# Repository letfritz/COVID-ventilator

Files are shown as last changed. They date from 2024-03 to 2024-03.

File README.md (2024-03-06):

# Technology at the service of life in combating the COVID-19 pandemic – UFF FRONT in the production of mechanical ventilators  

<div align="center"><br/>
  <div style="display: inline-block;">
    
    
    
  </div>
  <div style="display: inline-block;">
    
    
    
    
    
    
  </div>
</div><br/>

Arduino project for creating a mechanical ventilator for COVID patients.

## 📷 Screenshot
Electrical System Architecture:
electrical_system_architecture

Steps:
Steps

Volume Control State Machine:
Volume_Control_State_Machine

First prototype of a mechanical ventilator assembled at UFF. Emphasis on (a) the structural part of the equipment and (b) the control panel:
first

Detailing the control panel with controls for the Inspiration/Expiration (I/E) ratio, Air Volume Control, and ventilation frequency:
second

## Installation
1. Download the package to a local folder (e.g. ~/DER-SmartCampus/) by running:
  ```
    git clone https://github.com/letfritz/COVID-ventilator.git
  ```
2. Run Arduino IDE and navigate to the folder (~/main/), then run the main.ino script.

## Usage
  - See description in AnáliseDeRequisitos.docx.

## License
Released under MIT license.

## 📝 About this Project
The project aims primarily to promote the supply of emergency mechanical ventilation equipment, mainly for the public health system (SUS), to patients affected by comorbidities caused by COVID-19. These devices are necessary when severe pneumonia compromises lung function, and the breathing process is carried out with immense effort (dyspnea), reducing the concentration of dissolved oxygen in the blood (hypoxemia). In critical cases of COVID-19, intubation and immediate use of mechanical ventilation are indicated.

Initiatives around the world have emerged for the development of manual mechanical breathing units (AMBU). Some of the most famous examples are the projects developed at Oxford  and MIT ; in Brazil, projects such as the one from COPPE at UFRJ  and at USP  stand out. Among all these devices, the MIT model stands out for being a project that has undergone numerous tests and has been developed since 2010, featuring low-cost components. Additionally, after the onset of the pandemic, the working group has been making adaptations to make the project more robust and safe.

The E-Vent mechanical ventilator functions as a low-cost portable ventilator. Its main function is to assist the patient in breathing. Its construction uses few parts and has low manufacturing complexity. Mechanical force is exerted by a direct current motor coupled to a gear, which in turn moves the rods, compressing the AMBU, also known as a manual resuscitator or self-inflating bag. The AMBU is a manual device that provides positive pressure ventilation for patients who do not breathe or do so inadequately. The compression and expansion cycle of the AMBU, performed by the motor rotation, is controlled by the electronic part of the E-Vent and can be customized according to each patient's respiratory needs.

At UFF, adaptations to the E-Vent project have been developed. The main proposed changes are in the project's electronics and some adaptations in the mechanical structure to accommodate motors with other hole patterns and electrical specifications, which can be found domestically. A first prototype was built to evaluate the assembly and refine each part of the mechanical structure of the project. These parts will be manufactured using a CNC Machining Center to reduce costs with the projects. In addition, tests of precision in controlling the volume and pressure of the air pumped by the AMBU through motor rotation were also carried out during development.

The project is currently in the phase of building the second prototype and drafting a document to be submitted to ANVISA for certification of the final equipment. To do this, all standards regarding ventilation modes required by the agency will be followed so that the product can quickly meet the current demand.

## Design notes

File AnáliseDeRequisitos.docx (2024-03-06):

Componentes Eletrônicos

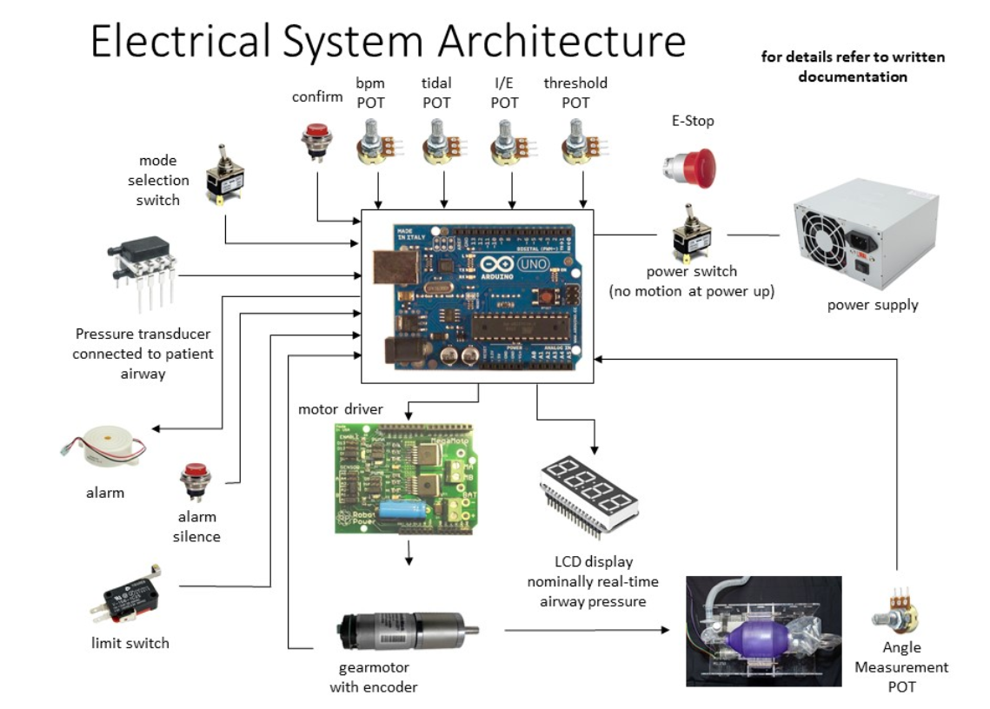
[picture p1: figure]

# 1 Materiais Listados para Uso

E-Vent MIT | E-Vent Adaptado | Função
Sensor Fim de Curso | Sensor Fim de Curso | Limitar a rotação do ponto de partida do motor
Botão de Alarme | Botão | Botão ao pressionar desliga o alarme
Alarme | Alarme | Alarme ao identificar falha
Transdutor de pressão conectado às vias aéreas do paciente | ? | Monitora a pressão que chega ao paciente
Chave de seleção | Chave de seleção | Seleção de modo do volume para auxiliar no controle.
Botão de Confirmação | Botão de Confirmação | Usado para confirmar uma alteração em um dos potenciômetros. Esse é um recurso de segurança necessário.
Potenciômetro (10 kΩ) BPM | Potenciômetro (10 kΩ) BPM | Varia o BPM. Isso define a taxa de 8 ao BPM máximo.
Potenciômetro (10 kΩ) Tidal | Potenciômetro (10 kΩ) Tidal | Varia o volume inspirado, define a oscilação angular dos braços. Durante a operação, cada braço varia aproximadamente um máximo de 20° (apertar totalmente uma bolsa grande). Este mostrador varia de posição de 0% (totalmente aberto) a 100% (totalmente compactado).
Potenciômetro (10 kΩ) I/E | Potenciômetro (10 kΩ) I/E | Varia a proporção I:E. Varia de 1:1 a 1:4.
Potenciômetro (10 kΩ) Threshold | Potenciômetro (10 kΩ) Threshold | Define o limite de pressão para detectar o controle de assistência.
Potenciômetro (10 kΩ) Ângulo | Potenciômetro (10 kΩ) Ângulo | ?
Botão E-Stop | Botão E-Stop | Desativa instantaneamente o sistema. Isso permitirá que a bolsa seja removida.
Chave de Energia | Chave de Energia | ON/OFF
Display LCD | Display LCD | Exibe a pressão das vias aéreas em cm H2O. Display LCD de 20 × 4 caracteres.
Drive do Motor | ?
Caixa de Redução do Motor com Encoder | ?
AMBU | AMBU | Pulmão artificial
Fonte | Fonte | Liga o sistema E-Vent

# 2 Metodologia

## 2.1 Estado de Controle de Volume

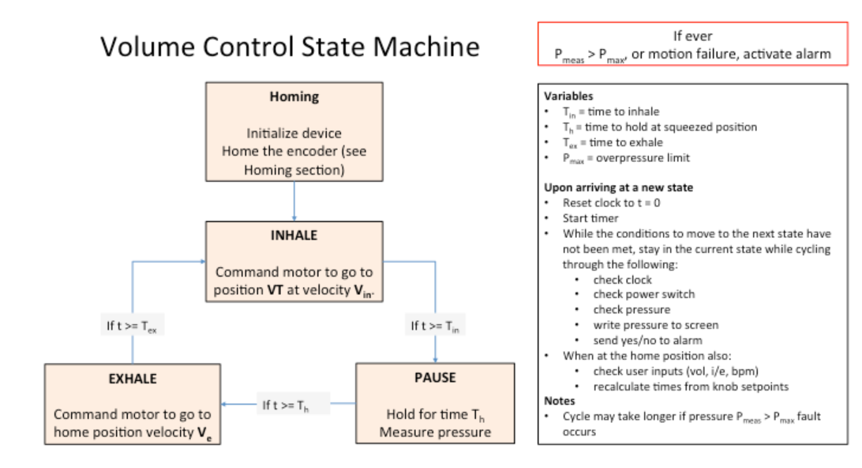
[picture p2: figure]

Tempo t é a quantidade de tempo gasto no estado atual.

### 2.1.1 Período (T)

O período de tempo (em segundos) de um ciclo de inspiração / expiração.

T=60/(BPM)

Sendo, BPM a respirações por minuto, também chamadas de frequência respiratória (RR). Geralmente varia entre 8-30 BPM. Isso é definido pelo potenciômetro.

### 2.1.2 Tin

O período de tempo (em segundos) da fase inspiratória.

T_(in) =T/((1+IE))

Sendo, IE a proporção entre Inspiração e Expiração definida pelo potenciômetro I:E. Por exemplo: se I/E é 1:3, então IE=3 .

### 2.1.3 Tex

O período de tempo (em segundos) da fase expiratória.

T_(ex) =T-T_(in)

### 2.1.4 Vin

A taxa de rotação da fase inspiratória (em pulsos / segundo).

V_(in) =(VT)/(T_(in))

## 2.2 Parâmetros Definidos pelo Usuário

### 2.2.1 Th

A quantidade de tempo (em segundos) para manter a compressão no final da inspiração para a pressão do platô.

### 2.2.2 Ve

A velocidade dos dedos na fase expiratória (em pulsos / segundo). Observe que, durante a expiração, nosso dispositivo não controla a vazão do paciente. Essa velocidade é simplesmente a velocidade da abertura dos dedos e não está relacionada à taxa de fluxo expiratório.

### 2.2.3 Pmax

A pressão máxima permitida (configurada para 40 cmH20).

### 2.2.4 Existem três parâmetros de pressão

Os parâmetros mensuráveis que devem ser levados em consideração

- Pip: Pressão máxima durante a inspiração. Consideramos 40 cmH20 o limite de pressão superior para segurança. Isso também corresponde ao limite da válvula de liberação de sobrepressão em alguns sacos Ambu.
- Pplat: A pressão de platô da inspiração. Um número de diagnóstico importante para os médicos.
- PEEP: A pressão residual no sistema após a expiração. Nós não controlamos diretamente esse valor, mas ele geralmente é controlado manualmente por meio de uma válvula PEEP no Ambu Bag.

## 2.3 Etapas

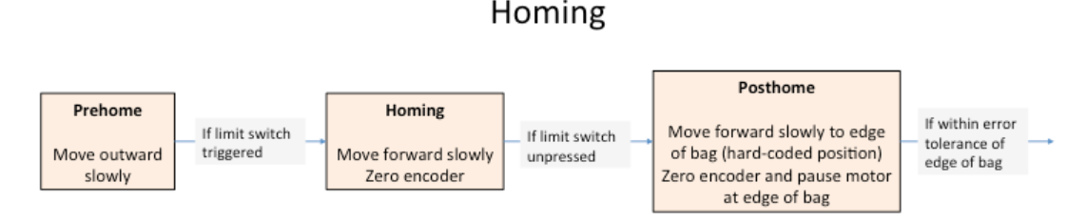
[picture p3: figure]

Durante a fase de configuração, inicializamos o programa, iniciamos a comunicação serial com o controlador do motor e inicializamos o codificador.

Na fase inspiratória, comandamos o motor para ir para a posição VT na velocidade Vin. Após Tin segundos, passamos para o estado de pausa.

No estado de pausa, mantemos o tempo Th e medimos a pressão do platô. Em seguida, passamos para a fase expiratória.

Na fase expiratória, comandamos o motor para ir para a posição 0 na velocidade Ve. Depois do tempo Tex, voltamos à fase inspiratória.

## 2.4 Pressão de Platô

Cada vez que os braços se fecham, implementamos uma pausa de 0,15s antes de abrir. Isso não afeta a razão I/E, mas é necessário reter o ar no paciente. Durante esta fase, a pressão das vias aéreas é medida e exibida. Isso indica "pressão de platô" e orientará a tomada de decisão clínica. Essa pressão será exibida até o próximo ciclo e atualização. Outras pressões são menos importantes, mas podem ser tratadas em uma estratégia de controle mais complicada.

## 2.5 Funções de alarmes

Todos os alarmes devem alertar o clínico de maneira simples, concisa e clara, para que o clínico possa decidir como proceder. Por exemplo, uma falha mecânica requer uma resposta clínica diferente da de um paciente que para de respirar no modo de assistência.

Lista de Alarmes:

Nome do Alarme | Detecção | Condição de Avaliação | Tom | Ação Clínica | Mensagem do Display LCD
Pressão PIP excedida | Isso garante que a unidade nunca possa fornecer ar a uma pressão superior a 40 cmH20 para reduzir o risco de barotrauma (danos nos pulmões). | Um ciclo respiratório completo sem pressão excessiva | Tom de emergência | Interrompa imediatamente a compressão, abra completamente, retome a operação normal no início do ciclo respiratório | ALTA PRESSÃO
Falha de Sobrecorrente | Este alarme detecta o motor sendo pressionado com muita força. Isso indica que algo pode estar preso no mecanismo ou pode haver um bloqueio no tubo respiratório. | Um ciclo respiratório completo sem evento de sobrecorrente | Tom de emergência | Interrompa imediatamente a compressão, abra completamente, retome a operação normal no início do ciclo respiratório | FALHA DE SOBRECORRENTE
Sob Pressão | Este alarme detecta qualquer desconexão ou vazamento e notifica o médico para verificar o tubo de respiração. | Pressão de platô medida normal | Tom de emergência | Continuar a operação normal | BAIXA PRESSÃO, DESCONECTADO?
Pressão de Condução Excedida | Este alarme notifica o clínico de que há resistência incomum no tubo respiratório ou nas vias aéreas do paciente. | Uma medição de pressão de condução na faixa normal | Notificação | Continue a operação normal | ELEVADO PICO DE PRESSÃO
Volume corrente não entregue | O codificador indica falha ao atingir a posição rotacional desejada | Volume corrente entregue na faixa correta | Tom de emergência | Continue a operação normal | VOLUME CORRENTE NÃO MEDIDO
Pressão corrente não detectada | Este alarme detecta situações em que a pressão não reflete inspiração, mas pode não haver um vazamento. Por exemplo, se a bolsa for removida da máquina. | Um ciclo respiratório completo sem falha da pressão corrente | Tom de emergência | Continue a operação normal | SEM PRESSÃO CORRENTE

## 2.6 Botão de Alarme

O botão de silêncio do alarme deve silenciar apenas o tom do alarme, a notificação visual deve permanecer. Todos os alarmes devem ser silenciados por dois minutos, mesmo que um novo alarme seja acionado, o silêncio do alarme deve ser mantido. Pressionar o botão de silêncio do alarme novamente, antes de decorridos dois minutos, deve silenciar os alarmes.

Se vários alarmes estiverem ativos, eles deverão ser exibidos visualmente com os LEDs. Na tela, as mensagens devem circular.

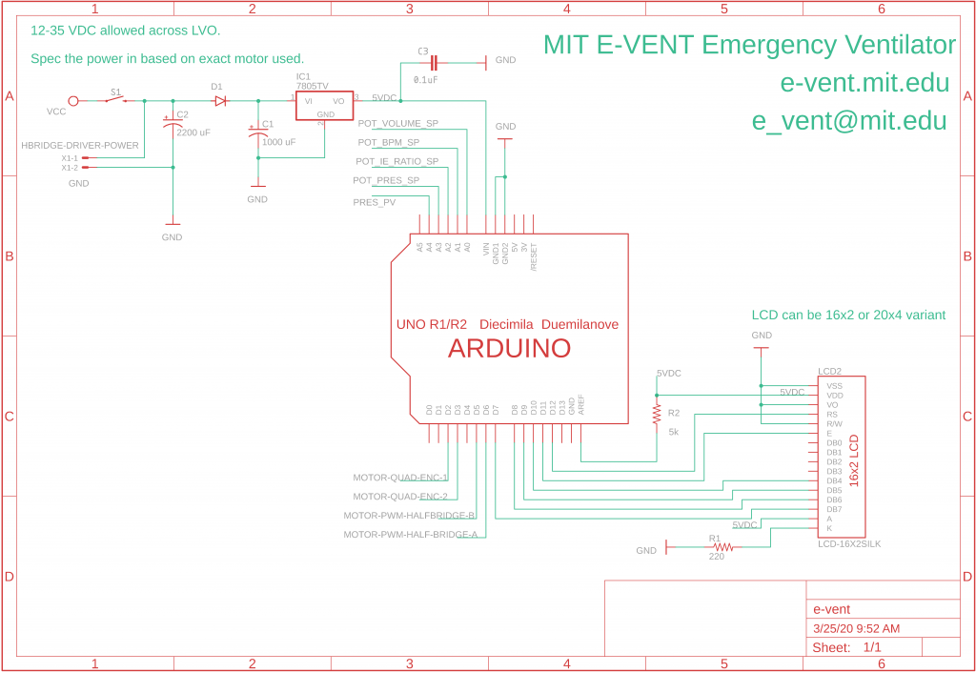
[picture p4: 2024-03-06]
Circuito_Eletronico/controls-schematic-arduino-hbridge-1024x706.png

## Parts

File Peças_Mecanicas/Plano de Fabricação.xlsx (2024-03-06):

PEÇA | QTD | MATERIAL | PROCESSO DE FABRICAÇÃO
001 | 2 | Acrílico | Corte
002 | 1 | Alumínio | Corte
003 | 20 | Acrílico | Corte
004 | 1 | Alumínio | Corte
005 | 1 | Acrílico | Corte
006 | 1 | Alumínio | Usinado
007 | 2 | Alumínio | Corte
008 | 2 | Alumínio | Usinado

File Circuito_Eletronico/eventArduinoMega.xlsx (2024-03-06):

Source: | /home/gscofano/Documentos/analise_circuitos/Respirador_MIT/original_01/eventArduinoMega.sch
Date: | Mon 20 Apr 2020 12:04:51 -03
Tool: | Eeschema 5.1.5-1.fc31
Generator: | /usr/share/kicad/plugins/bom_csv_grouped_by_value.py
Component Count: | 54
Individual Components:
Item | Qty | Reference(s) | Value | LibPart | Footprint | Datasheet
 |  | BZ1 | Buzzer | Device:Buzzer |  | ~
 |  | C1 | 1uF | Device:C | Capacitor_THT:C_Rect_L7.2mm_W2.5mm_P5.00mm_FKS2_FKP2_MKS2_MKP2 | ~
 |  | C2 | 1uF | Device:C | Capacitor_THT:C_Rect_L7.2mm_W2.5mm_P5.00mm_FKS2_FKP2_MKS2_MKP2 | ~
 |  | C3 | 1uF | Device:C | Capacitor_THT:C_Rect_L7.2mm_W2.5mm_P5.00mm_FKS2_FKP2_MKS2_MKP2 | ~
 |  | C4 | 100nF | Device:C | Capacitor_THT:C_Rect_L7.2mm_W2.5mm_P5.00mm_FKS2_FKP2_MKS2_MKP2 | ~
 |  | C5 | 1uF | Device:C | Capacitor_THT:C_Rect_L7.2mm_W2.5mm_P5.00mm_FKS2_FKP2_MKS2_MKP2 | ~
 |  | C6 | 100nF | Device:C | Capacitor_THT:C_Rect_L7.2mm_W2.5mm_P5.00mm_FKS2_FKP2_MKS2_MKP2 | ~
 |  | C7 | 1uF | Device:C | Capacitor_THT:C_Rect_L7.2mm_W2.5mm_P5.00mm_FKS2_FKP2_MKS2_MKP2 | ~
 |  | C8 | 1uF | Device:C | Capacitor_THT:C_Rect_L7.2mm_W2.5mm_P5.00mm_FKS2_FKP2_MKS2_MKP2 | ~
 |  | C9 | 1uF | Device:C | Capacitor_THT:C_Rect_L7.2mm_W2.5mm_P5.00mm_FKS2_FKP2_MKS2_MKP2 | ~
 |  | C10 | 100nF | Device:C | Capacitor_THT:C_Rect_L7.2mm_W2.5mm_P5.00mm_FKS2_FKP2_MKS2_MKP2 | ~
 |  | C11 | 100nF | Device:C | Capacitor_THT:C_Rect_L7.2mm_W2.5mm_P5.00mm_FKS2_FKP2_MKS2_MKP2 | ~
 |  | C12 | 100nF | Device:C | Capacitor_THT:C_Rect_L7.2mm_W2.5mm_P5.00mm_FKS2_FKP2_MKS2_MKP2 | ~
 |  | D1 | 1N60P | Device:D_Schottky |  | ~
 |  | D2 | 1N60P | Device:D_Schottky |  | ~
 |  | D3 | LED | Device:LED |  | ~
 |  | J1 | Screw_Terminal_01x03 | Connector:Screw_Terminal_01x03 |  | ~
 |  | J2 | Conn_01x16_Female | Connector:Conn_01x16_Female |  | ~
 |  | J3 | Screw_Terminal_01x04 | Connector:Screw_Terminal_01x04 |  | ~
 |  | J4 | Screw_Terminal_01x06 | Connector:Screw_Terminal_01x06 |  | ~
 |  | J5 | Screw_Terminal_01x04 | Connector:Screw_Terminal_01x04 |  | ~
 |  | R1 | 180R | Device:R | Resistor_THT:R_Axial_DIN0309_L9.0mm_D3.2mm_P12.70mm_Horizontal | ~
 |  | R2 | 10k | Device:R | Resistor_THT:R_Axial_DIN0309_L9.0mm_D3.2mm_P12.70mm_Horizontal | ~
 |  | R3 | 470R | Device:R | Resistor_THT:R_Axial_DIN0309_L9.0mm_D3.2mm_P12.70mm_Horizontal | ~
 |  | R4 | 220R | Device:R | Resistor_THT:R_Axial_DIN0309_L9.0mm_D3.2mm_P12.70mm_Horizontal | ~
 |  | R5 | 10k | Device:R | Resistor_THT:R_Axial_DIN0309_L9.0mm_D3.2mm_P12.70mm_Horizontal | ~
 |  | R6 | 330R | Device:R | Resistor_THT:R_Axial_DIN0309_L9.0mm_D3.2mm_P12.70mm_Horizontal | ~
 |  | R7 | 100k | Device:R | Resistor_THT:R_Axial_DIN0309_L9.0mm_D3.2mm_P12.70mm_Horizontal | ~
 |  | R8 | 10k | Device:R | Resistor_THT:R_Axial_DIN0309_L9.0mm_D3.2mm_P12.70mm_Horizontal | ~
 |  | R9 | 100k | Device:R | Resistor_THT:R_Axial_DIN0309_L9.0mm_D3.2mm_P12.70mm_Horizontal | ~
 |  | R10 | 100k | Device:R | Resistor_THT:R_Axial_DIN0309_L9.0mm_D3.2mm_P12.70mm_Horizontal | ~
 |  | R11 | 100k | Device:R | Resistor_THT:R_Axial_DIN0309_L9.0mm_D3.2mm_P12.70mm_Horizontal | ~
 |  | R12 | 100k | Device:R | Resistor_THT:R_Axial_DIN0309_L9.0mm_D3.2mm_P12.70mm_Horizontal | ~
 |  | R13 | 100k | Device:R | Resistor_THT:R_Axial_DIN0309_L9.0mm_D3.2mm_P12.70mm_Horizontal | ~
 |  | R14 | 100k | Device:R | Resistor_THT:R_Axial_DIN0309_L9.0mm_D3.2mm_P12.70mm_Horizontal | ~
 |  | R15 | 10k | Device:R | Resistor_THT:R_Axial_DIN0309_L9.0mm_D3.2mm_P12.70mm_Horizontal | ~
 |  | R16 | 270R | Device:R | Resistor_THT:R_Axial_DIN0309_L9.0mm_D3.2mm_P12.70mm_Horizontal | ~
 |  | R17 | 15R | Device:R | Resistor_THT:R_Axial_DIN0309_L9.0mm_D3.2mm_P12.70mm_Horizontal | ~
 |  | R18 | 470k | Device:R | Resistor_THT:R_Axial_DIN0309_L9.0mm_D3.2mm_P12.70mm_Horizontal | ~
 |  | R19 | 470k | Device:R | Resistor_THT:R_Axial_DIN0309_L9.0mm_D3.2mm_P12.70mm_Horizontal | ~
 |  | RV1 | R_POT_US | Device:R_POT_US | prototypeParts:pot_panel_surface | ~
 |  | RV2 | R_POT_US | Device:R_POT_US | prototypeParts:pot_panel_surface | ~
 |  | RV3 | R_POT_US | Device:R_POT_US | prototypeParts:pot_panel_surface | ~
 |  | RV4 | R_POT_US | Device:R_POT_US | prototypeParts:pot_panel_surface | ~
 |  | SW1 | SW_SPST | Switch:SW_SPST |  | ~
 |  | SW2 | SW_SPST | Switch:SW_SPST |  | ~
 |  | SW3 | SW_SPST | Switch:SW_SPST |  | ~
 |  | SW4 | SW_SPST | Switch:SW_SPST |  | ~
 |  | U1 | L7805 | Regulator_Linear:L7805 | prototypeParts:TO-220-3_Widened_Vertical | http://www.st.com/content/ccc/resource/technical/document/datasheet/41/4f/b3/b0/12/d4/47/88/CD00000444.pdf/files/CD00000444.pdf/jcr:content/translations/en.CD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
 |  | U2 | microSDpololu | eventArduinoMega-rescue:microSDpololu-mikeShit | prototypeParts:microSDpololuBoard
 |  | U3 | TL082 | Amplifier_Operational:TL082 |  | http://www.ti.com/lit/ds/symlink/tl081.pdf
 |  | U4 | TL082 | Amplifier_Operational:TL082 |  | http://www.ti.com/lit/ds/symlink/tl081.pdf
 |  | U5 | INA126 | Amplifier_Instrumentation:INA128 |  | https://www.ti.com/lit/ds/symlink/ina126.pdf
 |  | XA1 | Arduino_Mega2560_Shield | eventArduinoMega-rescue:Arduino_Mega2560_Shield-arduino-eventArduinoMega-rescue | ArduinoMegaHoleLess:Arduino_Mega2560_Shield | https://store.arduino.cc/arduino-mega-2560-rev3
 |  |  | Screw_Terminal_01x04
 |  |  | Encoder incremental
 |  |  | LCD 16x2
 |  |  | Mpx10dp
 |  |  | Placa de fenolite 20x20 cm
Collated Components:
Item | Qty | Reference(s) | Value | LibPart | Footprint | Datasheet
1 | 1 | BZ1 | Buzzer | Device:Buzzer |  | ~
2 | 7 | C1, C2, C3, C5, C7, C8, C9 | 1uF | Device:C | Capacitor_THT:C_Rect_L7.2mm_W2.5mm_P5.00mm_FKS2_FKP2_MKS2_MKP2 | ~
3 | 5 | C4, C6, C10, C11, C12 | 100nF | Device:C | Capacitor_THT:C_Rect_L7.2mm_W2.5mm_P5.00mm_FKS2_FKP2_MKS2_MKP2 | ~
4 | 2 | D1, D2 | 1N60P | Device:D_Schottky |  | ~
5 | 1 | D3 | LED | Device:LED |  | ~
6 | 1 | J1 | Screw_Terminal_01x03 | Connector:Screw_Terminal_01x03 |  | ~
7 | 1 | J2 | Conn_01x16_Female | Connector:Conn_01x16_Female |  | ~
8 | 3 | J3, J5 | Screw_Terminal_01x04 | Connector:Screw_Terminal_01x04 |  | ~
9 | 1 | J4 | Screw_Terminal_01x06 | Connector:Screw_Terminal_01x06 |  | ~
10 | 1 | R1 | 180R | Device:R | Resistor_THT:R_Axial_DIN0309_L9.0mm_D3.2mm_P12.70mm_Horizontal | ~
11 | 4 | R2, R5, R8, R15 | 10k | Device:R | Resistor_THT:R_Axial_DIN0309_L9.0mm_D3.2mm_P12.70mm_Horizontal | ~
12 | 1 | R3 | 470R | Device:R | Resistor_THT:R_Axial_DIN0309_L9.0mm_D3.2mm_P12.70mm_Horizontal | ~
13 | 1 | R4 | 220R | Device:R | Resistor_THT:R_Axial_DIN0309_L9.0mm_D3.2mm_P12.70mm_Horizontal | ~
14 | 1 | R6 | 330R | Device:R | Resistor_THT:R_Axial_DIN0309_L9.0mm_D3.2mm_P12.70mm_Horizontal | ~
15 | 7 | R7, R9, R10, R11, R12, R13, R14 | 100k | Device:R | Resistor_THT:R_Axial_DIN0309_L9.0mm_D3.2mm_P12.70mm_Horizontal | ~
16 | 1 | R16 | 270R | Device:R | Resistor_THT:R_Axial_DIN0309_L9.0mm_D3.2mm_P12.70mm_Horizontal | ~
17 | 1 | R17 | 15R | Device:R | Resistor_THT:R_Axial_DIN0309_L9.0mm_D3.2mm_P12.70mm_Horizontal | ~
18 | 2 | R18, R19 | 470k | Device:R | Resistor_THT:R_Axial_DIN0309_L9.0mm_D3.2mm_P12.70mm_Horizontal | ~
19 | 4 | RV1, RV2, RV3, RV4 | R_POT_US | Device:R_POT_US | prototypeParts:pot_panel_surface | ~
20 | 4 | SW1, SW2, SW3, SW4 | SW_SPST | Switch:SW_SPST |  | ~
21 | 1 | U1 | L7805 | Regulator_Linear:L7805 | prototypeParts:TO-220-3_Widened_Vertical | http://www.st.com/content/ccc/resource/technical/document/datasheet/41/4f/b3/b0/12/d4/47/88/CD00000444.pdf/files/CD00000444.pdf/jcr:content/translations/en.CD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
22 | 1 | U2 | microSDpololu | eventArduinoMega-rescue:microSDpololu-mikeShit | prototypeParts:microSDpololuBoard
23 | 2 | U3, U4 | TL082 | Amplifier_Operational:TL082 |  | http://www.ti.com/lit/ds/symlink/tl081.pdf
24 | 1 | U5 | INA126 | Amplifier_Instrumentation:INA128 |  | https://www.ti.com/lit/ds/symlink/ina126.pdf
25 | 1 | XA1 | Arduino_Mega2560_Shield | eventArduinoMega-rescue:Arduino_Mega2560_Shield-arduino-eventArduinoMega-rescue | ArduinoMegaHoleLess:Arduino_Mega2560_Shield | https://store.arduino.cc/arduino-mega-2560-rev3
26 | 1 |  | Encoder incremental
27 | 1 |  | LCD 16x2
28 | 1 |  | Mpx10dp
 | 1 |  | Placa de fenolite 20x20 cm

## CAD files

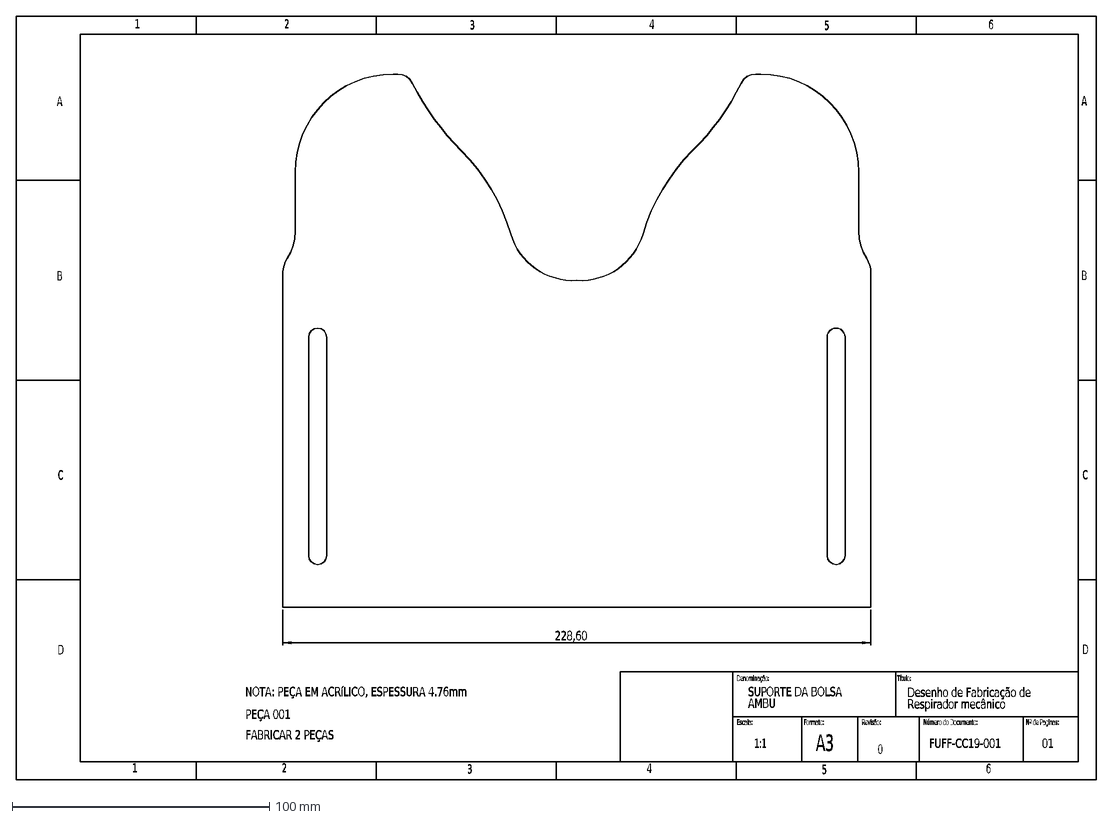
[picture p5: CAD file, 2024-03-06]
Peças_Mecanicas/Peças de acrilico/Peça 001 - Corte/Bag Support End - 001.DXF
NOTA: PEÇA EM ACRíLICO, ESPESSURA 4.76mm
Desenho de Fabricação de
Respirador mecânico
FUFF-CC19-001
0
01
1:1
SUPORTE DA BOLSA
AMBU
PEÇA 001
FABRICAR 2 PEÇAS
A3
Nº de Paginas:
Número do Documento:
Revisão:
Formato:
Escala:
Título:
Denominação:
D
C
B
A
1
2
6
5
3
4
228,60

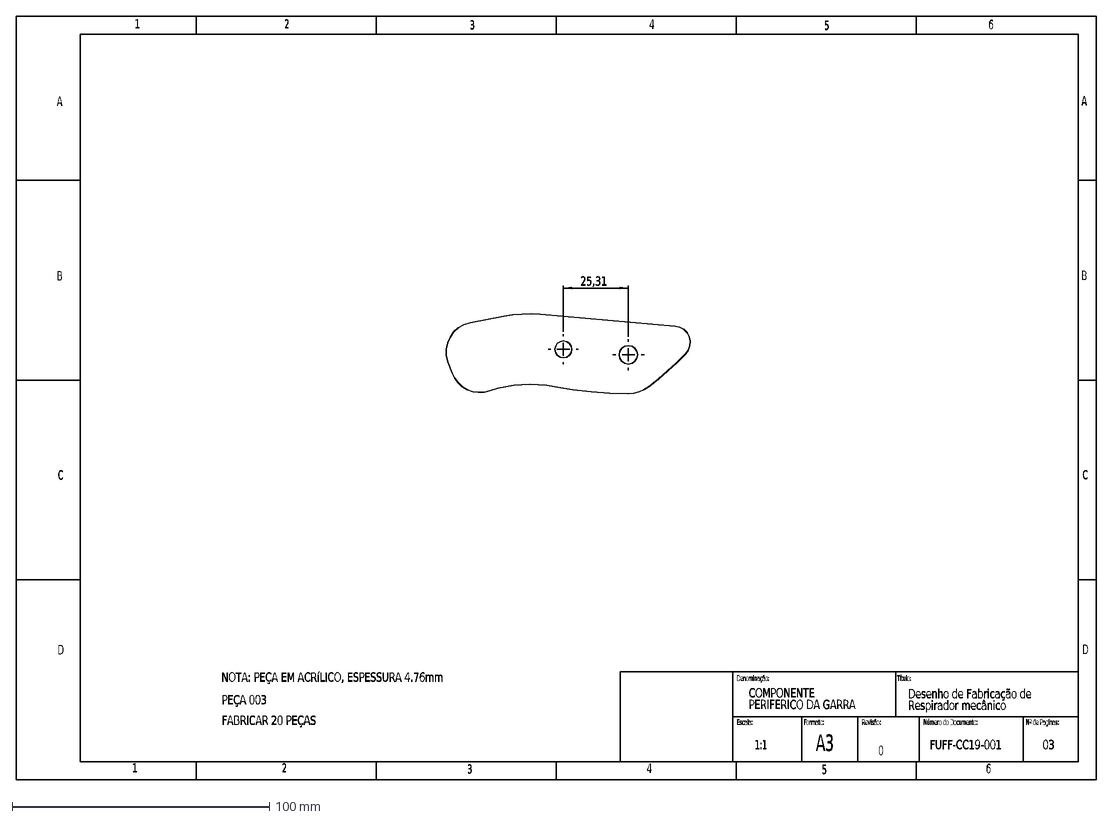
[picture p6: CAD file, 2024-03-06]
Peças_Mecanicas/Peças de acrilico/Peça 003 - Corte/Finger Tip - 003.DXF
FABRICAR 20 PEÇAS
PEÇA 003
NOTA: PEÇA EM ACRíLICO, ESPESSURA 4.76mm
COMPONENTE
PERIFERICO DA GARRA
1:1
03
0
FUFF-CC19-001
Desenho de Fabricação de
Respirador mecânico
A3
Nº de Paginas:
Número do Documento:
Revisão:
Formato:
Escala:
Título:
Denominação:
D
C
B
A
1
2
6
5
3
4
25,31

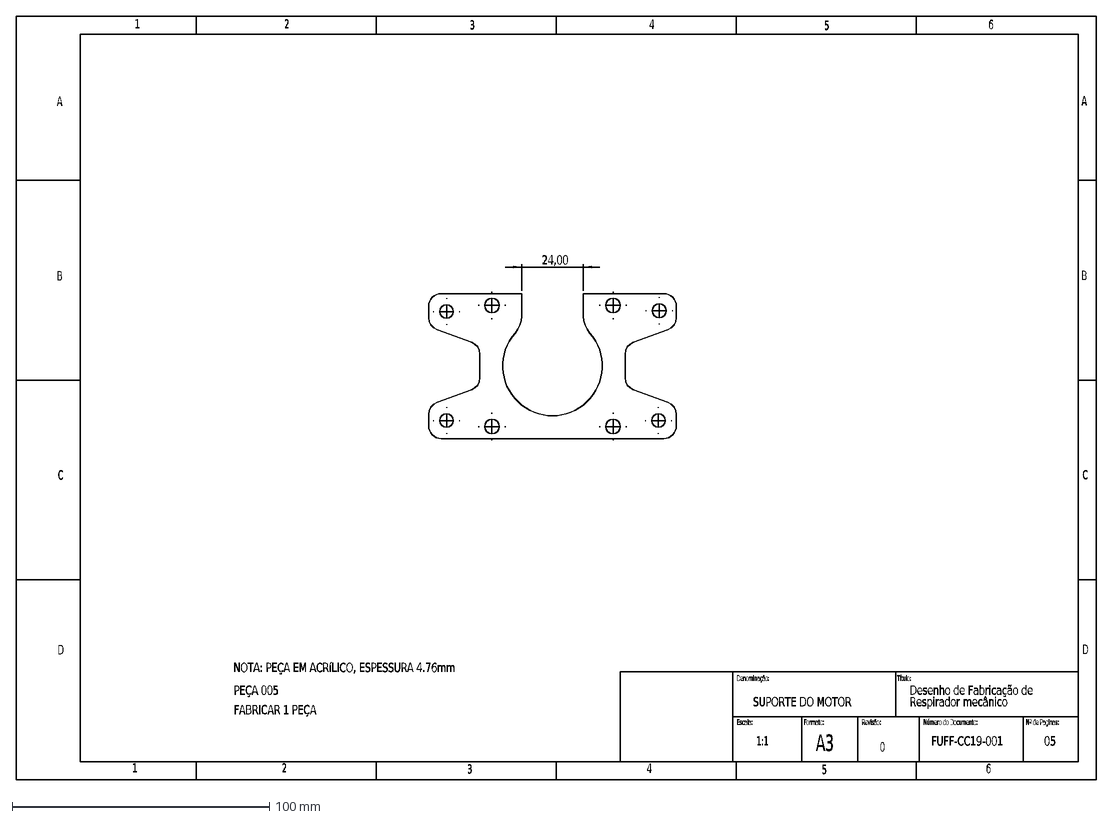
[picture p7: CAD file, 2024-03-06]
Peças_Mecanicas/Peças de acrilico/Peça 005 - Corte/Suporte do motor_V1.0 - 005.DXF
FABRICAR 1 PEÇA
PEÇA 005
NOTA: PEÇA EM ACRíLICO, ESPESSURA 4.76mm
SUPORTE DO MOTOR
1:1
05
0
FUFF-CC19-001
Desenho de Fabricação de
Respirador mecânico
A3
Nº de Paginas:
Número do Documento:
Revisão:
Formato:
Escala:
Título:
Denominação:
D
C
B
A
1
2
6
5
3
4
24,00

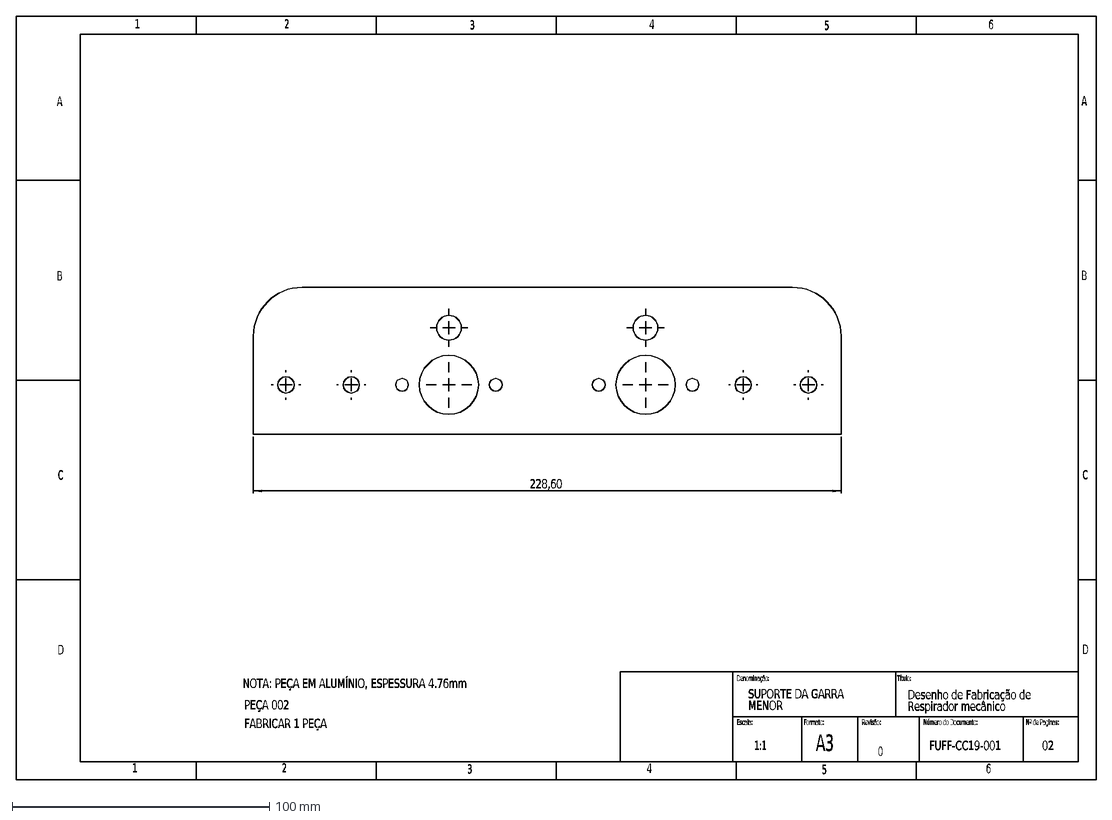
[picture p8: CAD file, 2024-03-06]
Peças_Mecanicas/Peças de Aluminio/Peça 002 - Corte/Finger Mount - 002.DXF
SUPORTE DA GARRA
MENOR
1:1
02
0
FUFF-CC19-001
Desenho de Fabricação de
Respirador mecânico
NOTA: PEÇA EM ALUMÍNIO, ESPESSURA 4.76mm
PEÇA 002
FABRICAR 1 PEÇA
A3
Nº de Paginas:
Número do Documento:
Revisão:
Formato:
Escala:
Título:
Denominação:
D
C
B
A
1
2
6
5
3
4
228,60

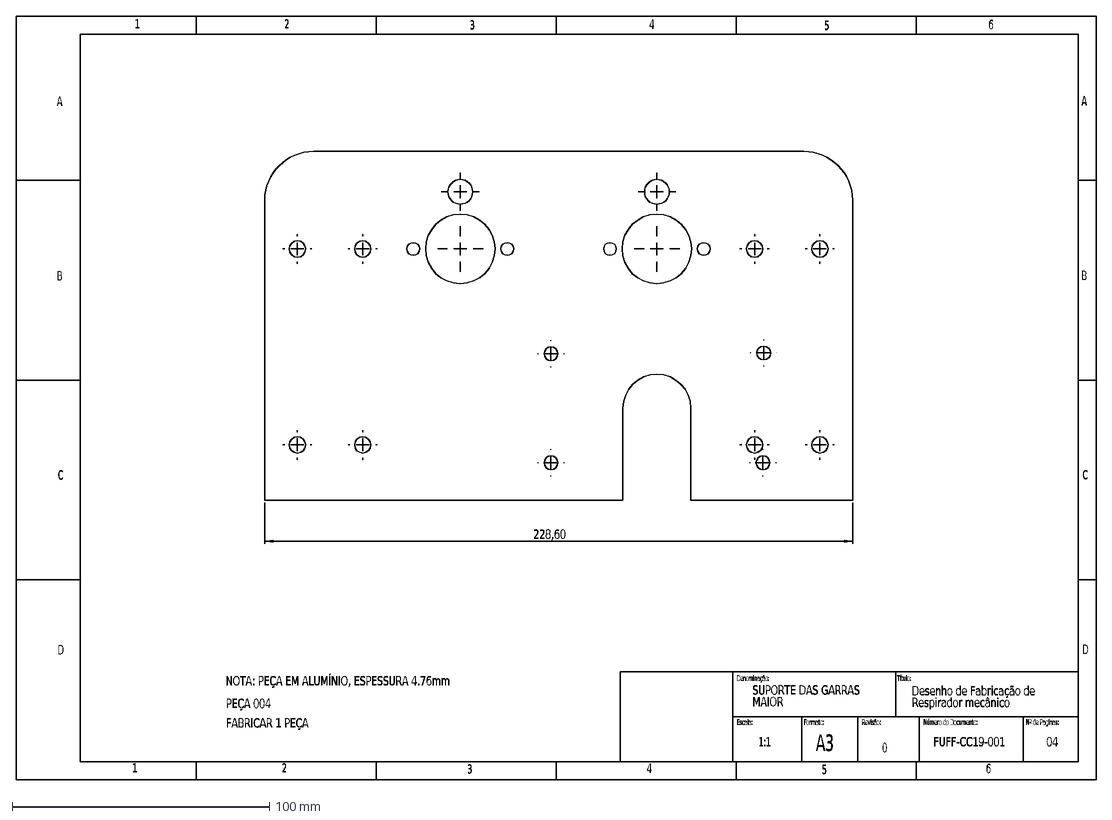
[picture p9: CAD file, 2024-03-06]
Peças_Mecanicas/Peças de Aluminio/Peça 004 - Corte/Motor and Finger Mount - 004.DXF
NOTA: PEÇA EM ALUMÍNIO, ESPESSURA 4.76mm
PEÇA 004
FABRICAR 1 PEÇA
Desenho de Fabricação de
Respirador mecânico
FUFF-CC19-001
0
04
1:1
SUPORTE DAS GARRAS
MAIOR
A3
Nº de Paginas:
Número do Documento:
Revisão:
Formato:
Escala:
Título:
Denominação:
D
C
B
A
1
2
6
5
3
4
228,60

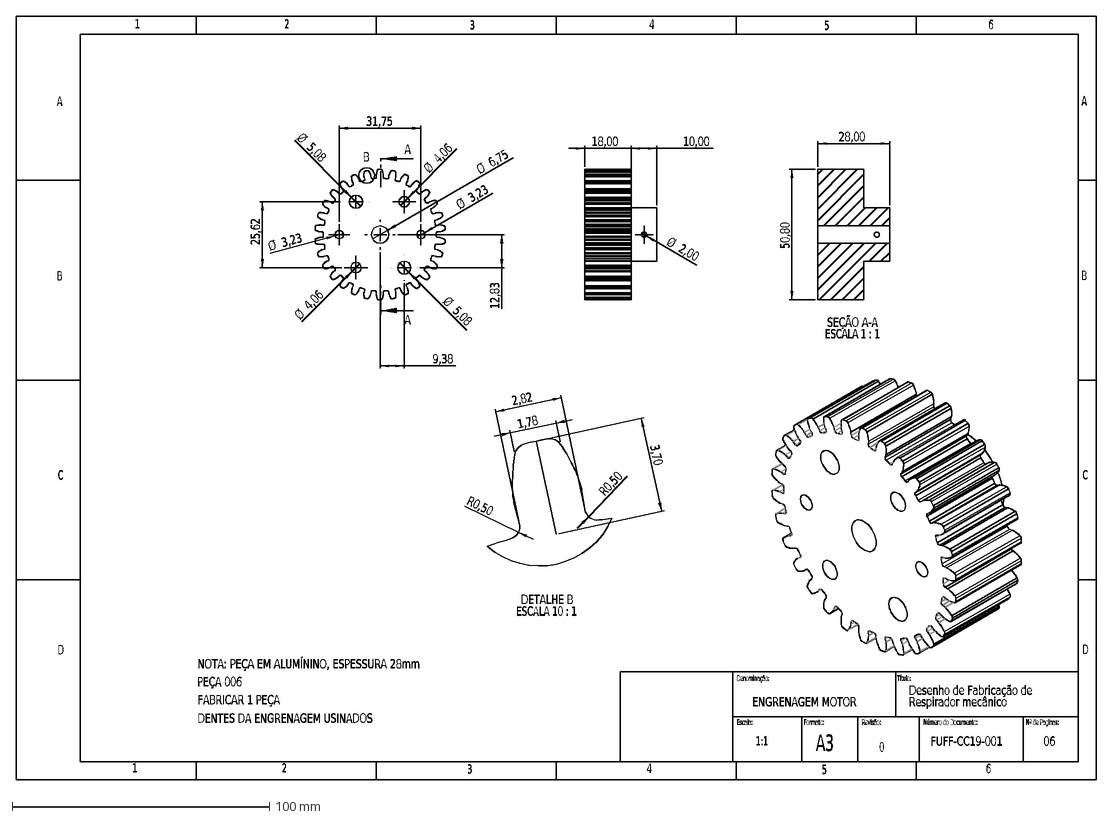
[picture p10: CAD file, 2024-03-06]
Peças_Mecanicas/Peças de Aluminio/Peça 006 - Usinado/engrenagem - 006.DXF
NOTA: PEÇA EM ALUMÍNINO, ESPESSURA 28mm
PEÇA 006
FABRICAR 1 PEÇA
Desenho de Fabricação de
Respirador mecânico
FUFF-CC19-001
0
06
1:1
ENGRENAGEM MOTOR
DENTES DA ENGRENAGEM USINADOS
A3
Nº de Paginas:
Número do Documento:
Revisão:
Formato:
Escala:
Título:
Denominação:
D
C
B
A
1
2
6
5
3
4
12,83
9,38
31,75
25,62
Ø
4,06
5,08
3,23
6,75
10,00
18,00
2,00
28,00
50,80
SEÇÃO A-A
ESCALA 1 : 1
3,70
R0,50
2,82
1,78
DETALHE B
ESCALA 10 : 1

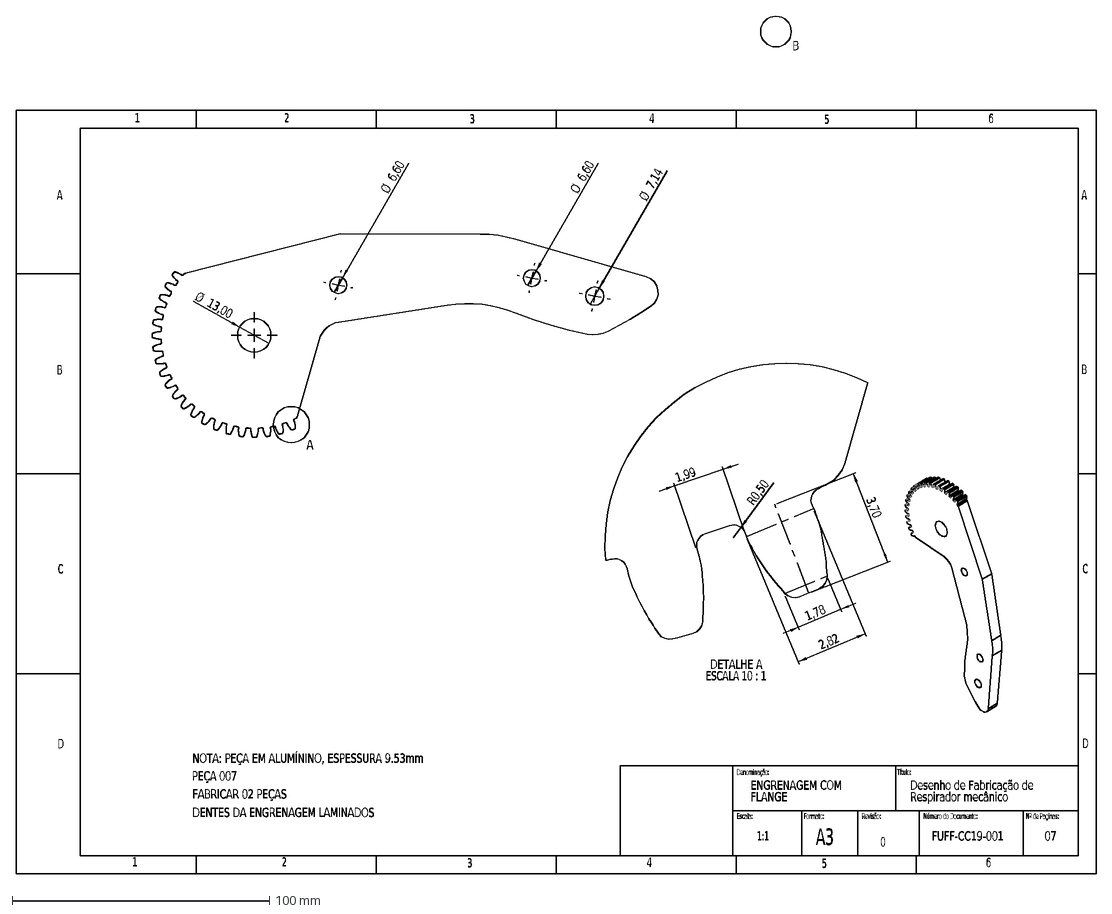
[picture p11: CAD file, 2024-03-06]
Peças_Mecanicas/Peças de Aluminio/Peça 007 - Corte/Finger - 007.DXF
DENTES DA ENGRENAGEM LAMINADOS
FABRICAR 02 PEÇAS
PEÇA 007
NOTA: PEÇA EM ALUMÍNINO, ESPESSURA 9.53mm
ENGRENAGEM COM
FLANGE
1:1
07
0
FUFF-CC19-001
Desenho de Fabricação de
Respirador mecânico
A3
Nº de Paginas:
Número do Documento:
Revisão:
Formato:
Escala:
Título:
Denominação:
D
C
B
A
1
2
6
5
3
4
Ø
6,60
7,14
13,00
2,82
3,70
1,78
1,99
R0,50
DETALHE A
ESCALA 10 : 1

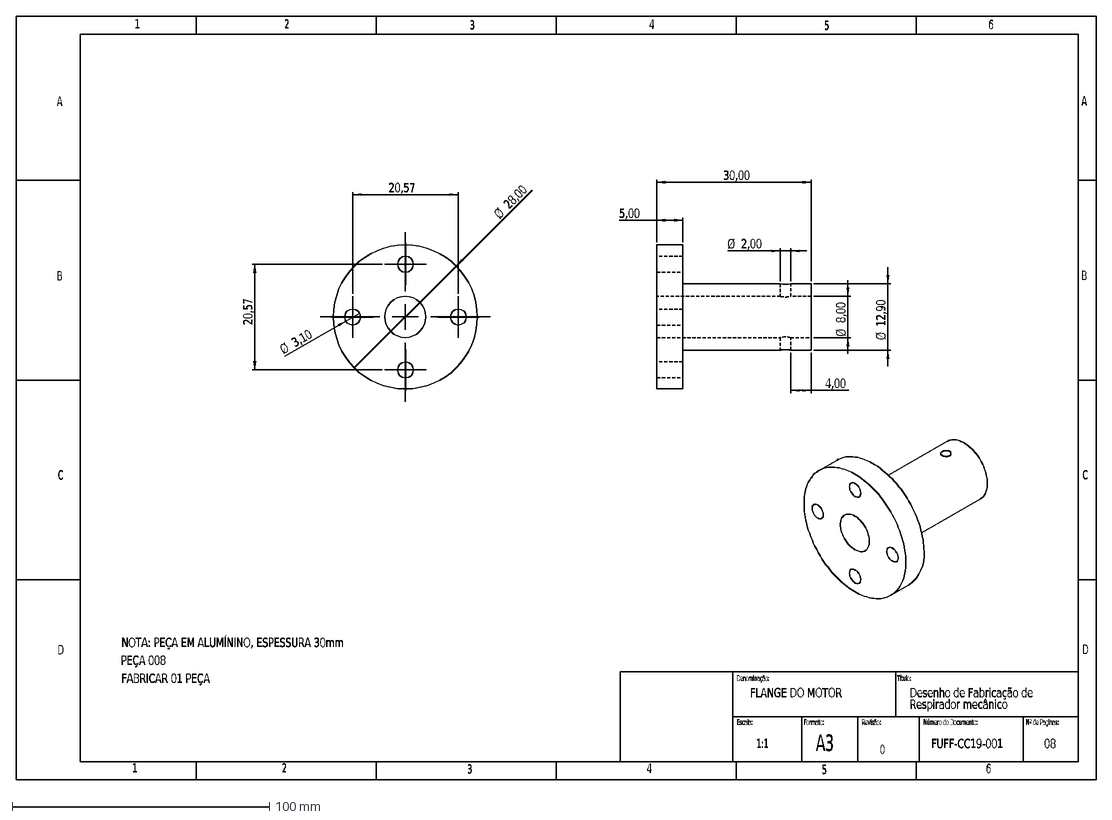
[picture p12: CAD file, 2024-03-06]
Peças_Mecanicas/Peças de Aluminio/Peça 008 - Usinado/Flange_finger - 008.DXF
NOTA: PEÇA EM ALUMÍNINO, ESPESSURA 30mm
PEÇA 008
FABRICAR 01 PEÇA
Desenho de Fabricação de
Respirador mecânico
FUFF-CC19-001
0
08
1:1
FLANGE DO MOTOR
A3
Nº de Paginas:
Número do Documento:
Revisão:
Formato:
Escala:
Título:
Denominação:
D
C
B
A
1
2
6
5
3
4
Ø
28,00
3,10
20,57
30,00
12,90
2,00
4,00
5,00
8,00

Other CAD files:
Peças_Mecanicas/Peças de Aluminio/Peça 002 - Corte/Finger Mount - 002.SLDDRW
Peças_Mecanicas/Peças de Aluminio/Peça 004 - Corte/Motor and Finger Mount - 004.SLDDRW
Peças_Mecanicas/Peças de Aluminio/Peça 006 - Usinado/engrenagem - 006.SLDDRW
Peças_Mecanicas/Peças de Aluminio/Peça 007 - Corte/Finger - 007.SLDDRW
Peças_Mecanicas/Peças de Aluminio/Peça 008 - Usinado/Flange_finger - 008.SLDDRW
Peças_Mecanicas/Peças de acrilico/Peça 001 - Corte/Bag Support End - 001.SLDDRW
Peças_Mecanicas/Peças de acrilico/Peça 003 - Corte/Finger Tip - 003.SLDDRW
Peças_Mecanicas/Peças de acrilico/Peça 005 - Corte/Suporte do motor_V1.0 - 005.SLDDRW

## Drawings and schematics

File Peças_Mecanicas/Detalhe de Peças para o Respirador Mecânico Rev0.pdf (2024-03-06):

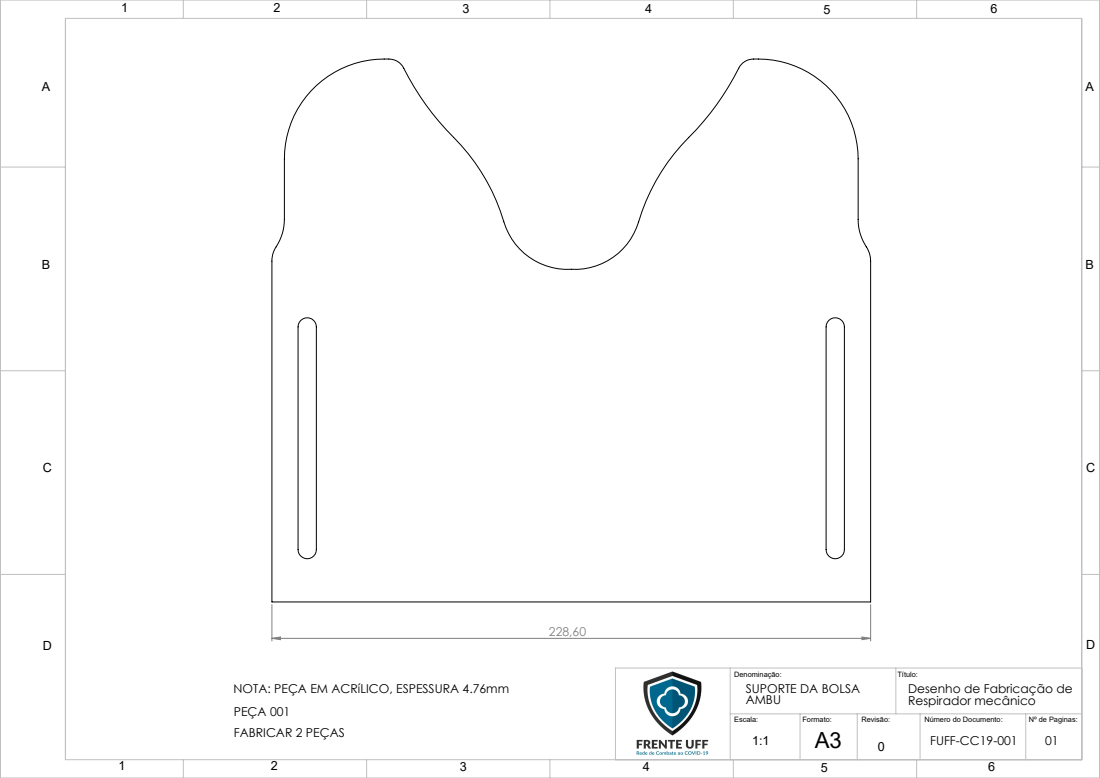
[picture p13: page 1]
NOTA: PEÇA EM ACRíLICO, ESPESSURA 4.76mm; Desenho de Fabricação de; PEÇA 001; FABRICAR 2 PEÇAS

Denominação: SUPORTE DA BOLSA AMBU | Título: Respirador mecânico

Escala: 1:1 | Formato: | Revisão: 0 | Número do Documento: FUFF-CC19-001 | Nº de Paginas: 01

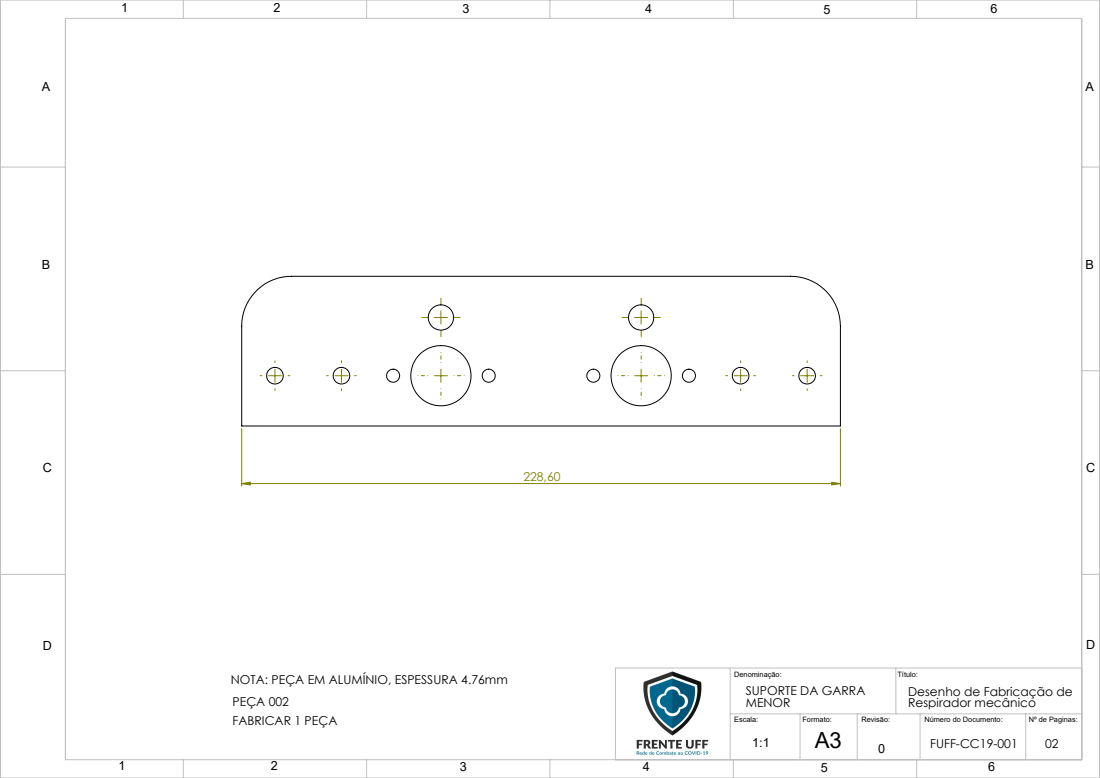
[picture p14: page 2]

NOTA: PEÇA EM ALUMÍNIO, ESPESSURA 4.76mm
PEÇA 002
FABRICAR 1 PEÇA

Denominação: SUPORTE DA GARRA MENOR | Título: Desenho de Fabricação de Respirador mecânico

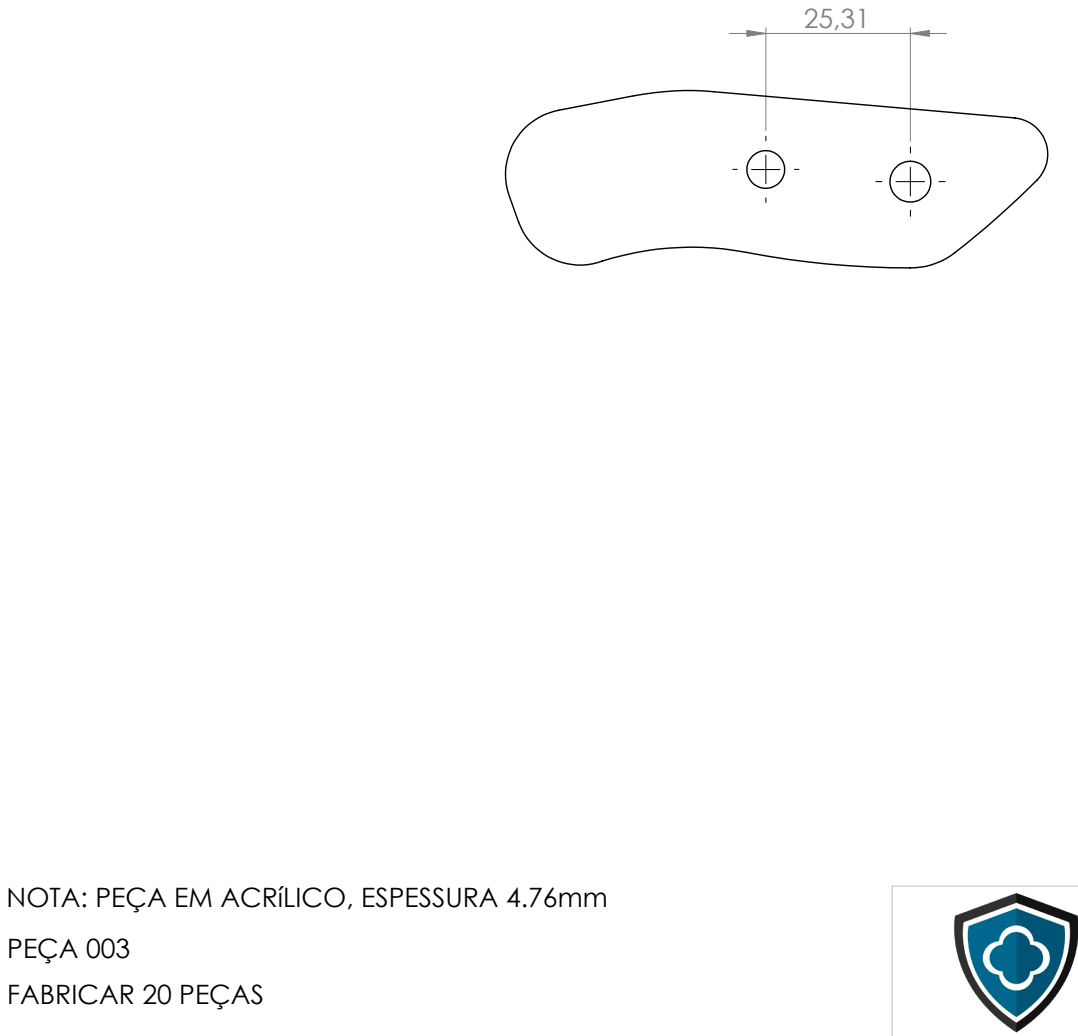
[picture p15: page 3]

NOTA: PEÇA EM ACRíLICO, ESPESSURA 4.76mm
PEÇA 003
FABRICAR 20 PEÇAS

Denominação: COMPONENTE PERIFERICO DA GARRA | Título: Desenho de Fabricação de Respirador mecânico

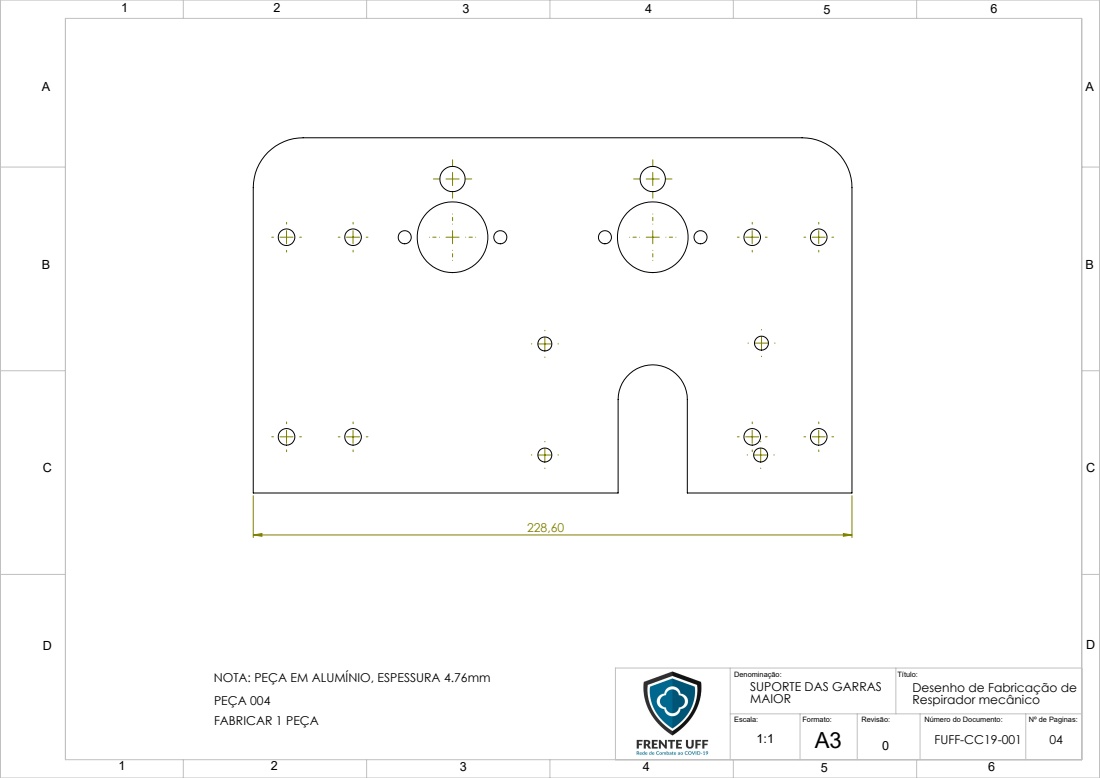
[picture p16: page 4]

NOTA: PEÇA EM ALUMÍNIO, ESPESSURA 4.76mm
PEÇA 004
FABRICAR 1 PEÇA

Denominação: SUPORTE DAS GARRAS MAIOR | Título: Desenho de Fabricação de Respirador mecânico

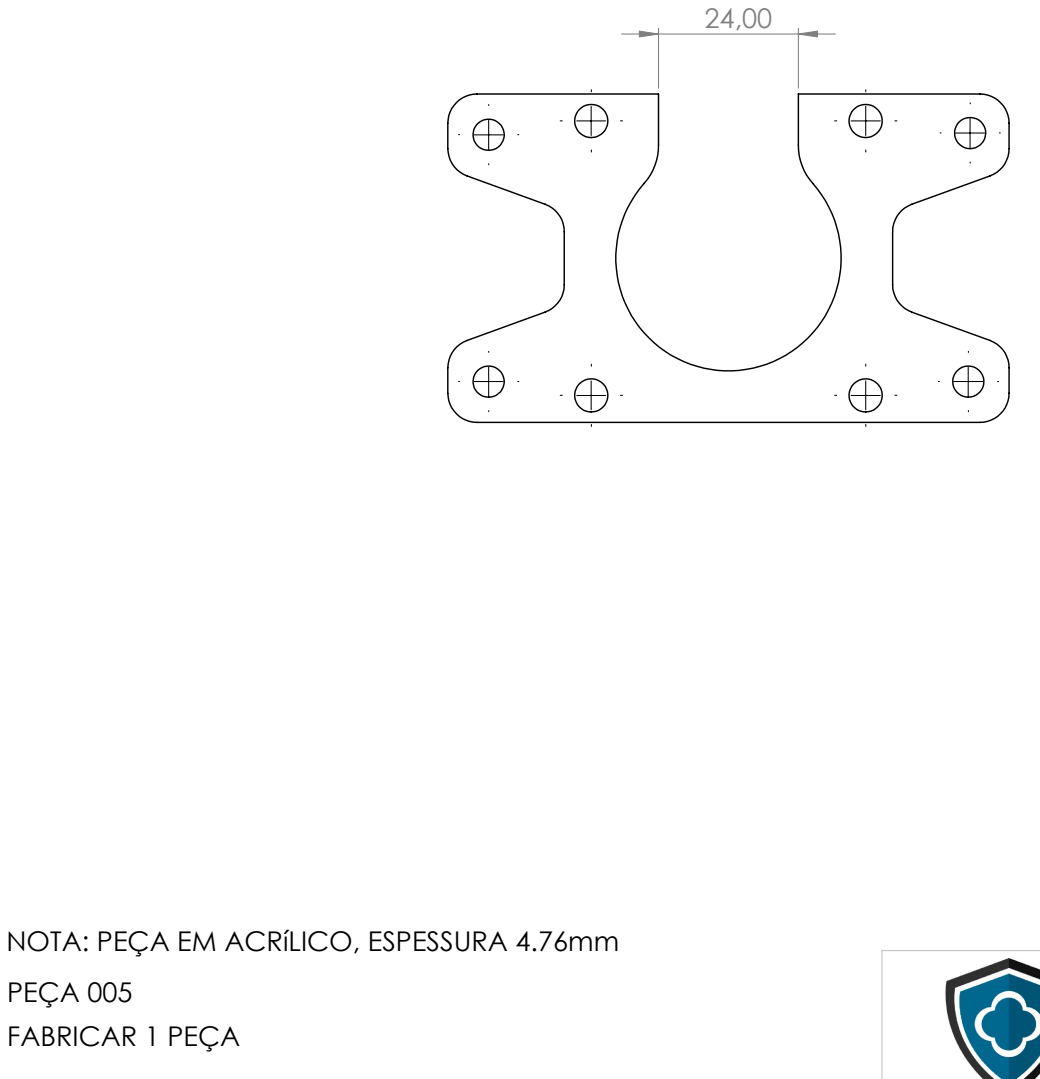
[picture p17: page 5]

NOTA: PEÇA EM ACRíLICO, ESPESSURA 4.76mm
PEÇA 005
FABRICAR 1 PEÇA

Denominação: SUPORTE DO MOTOR | Título: Desenho de Fabricação de Respirador mecânico

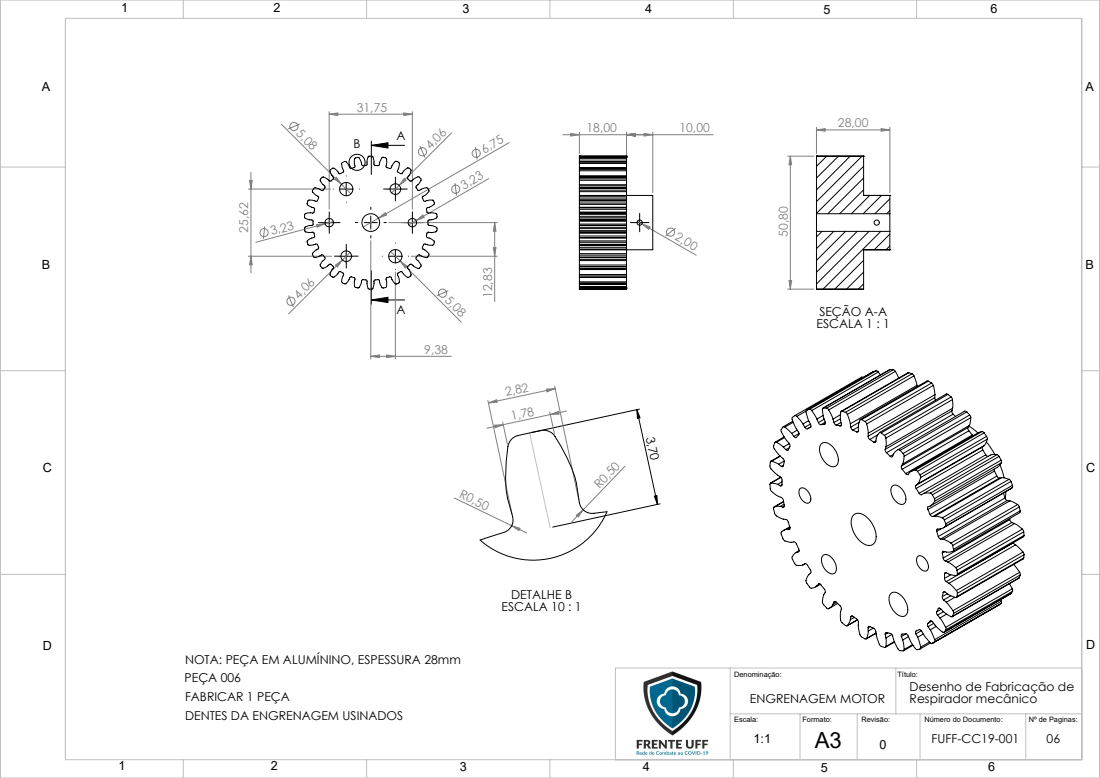
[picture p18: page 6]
SEÇÃO A-A ESCALA 1 : 1; DETALHE B ESCALA 10 : 1

NOTA: PEÇA EM ALUMÍNINO, ESPESSURA 28mm
PEÇA 006
FABRICAR 1 PEÇA
DENTES DA ENGRENAGEM USINADOS

Denominação: ENGRENAGEM MOTOR | Título: Desenho de Fabricação de Respirador mecânico

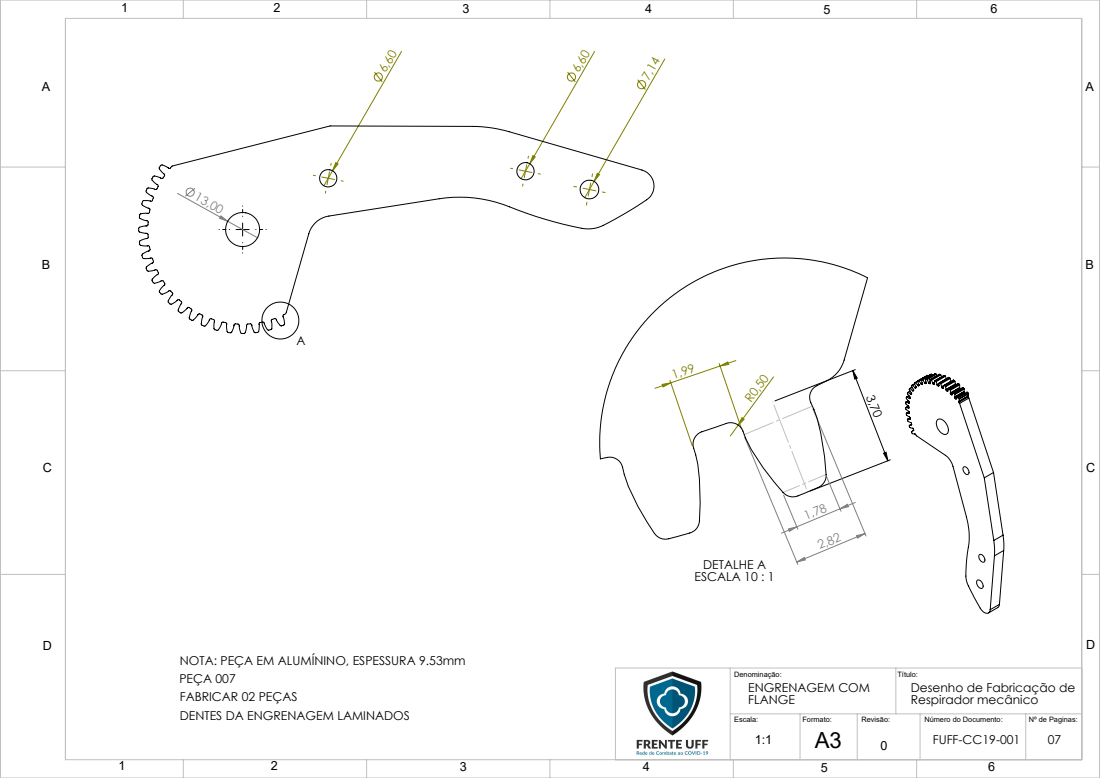
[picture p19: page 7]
DETALHE A ESCALA 10 : 1

NOTA: PEÇA EM ALUMÍNINO, ESPESSURA 9.53mm
PEÇA 007
FABRICAR 02 PEÇAS
DENTES DA ENGRENAGEM LAMINADOS

Denominação: ENGRENAGEM COM FLANGE | Título: Desenho de Fabricação de Respirador mecânico

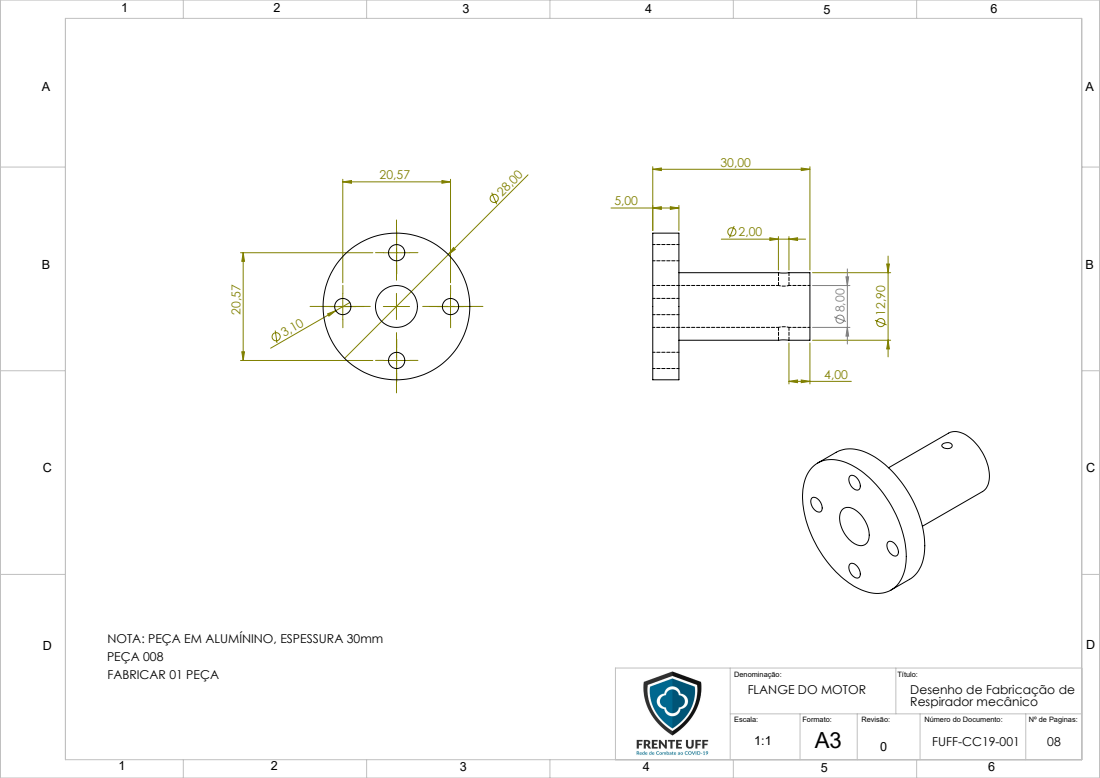
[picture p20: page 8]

NOTA: PEÇA EM ALUMÍNINO, ESPESSURA 30mm
PEÇA 008
FABRICAR 01 PEÇA

Denominação: FLANGE DO MOTOR | Título: Desenho de Fabricação de Respirador mecânico

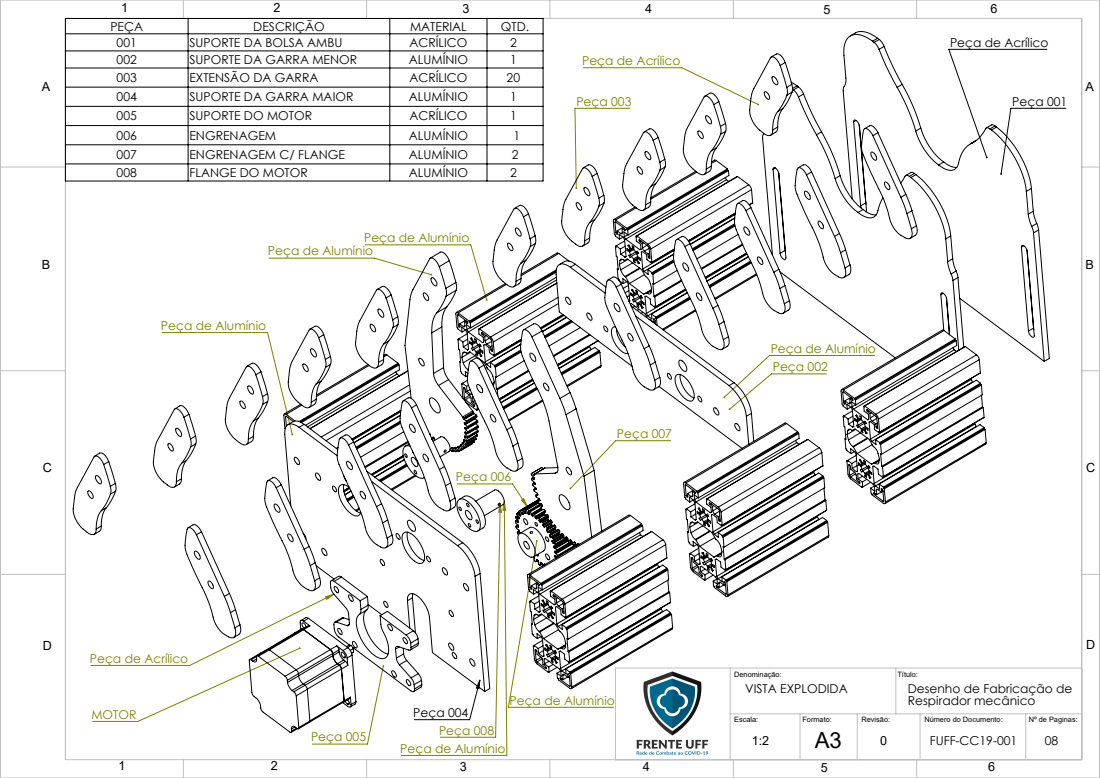
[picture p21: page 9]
MOTOR; Peça 001; Peça 003; Peça 005; Peça 006; Peça 007

PEÇA | DESCRIÇÃO | MATERIAL | QTD.
001 | SUPORTE DA BOLSA AMBU | ACRÍLICO | 2
002 | SUPORTE DA GARRA MENOR | ALUMÍNIO | 1
003 | EXTENSÃO DA GARRA | ACRÍLICO | 20
004 | SUPORTE DA GARRA MAIOR | ALUMÍNIO | 1
005 | SUPORTE DO MOTOR | ACRÍLICO | 1
006 | ENGRENAGEM | ALUMÍNIO | 1
007 | ENGRENAGEM C/ FLANGE | ALUMÍNIO | 2
008 | FLANGE DO MOTOR | ALUMÍNIO | 2

Peça de Acrílico

Peça de Alumínio

Peça 002

Denominação: VISTA EXPLODIDA | Título: Desenho de Fabricação de Respirador mecânico

Peça 004
Peça 008

1:2 | | 0 | FUFF-CC19-001 | 08

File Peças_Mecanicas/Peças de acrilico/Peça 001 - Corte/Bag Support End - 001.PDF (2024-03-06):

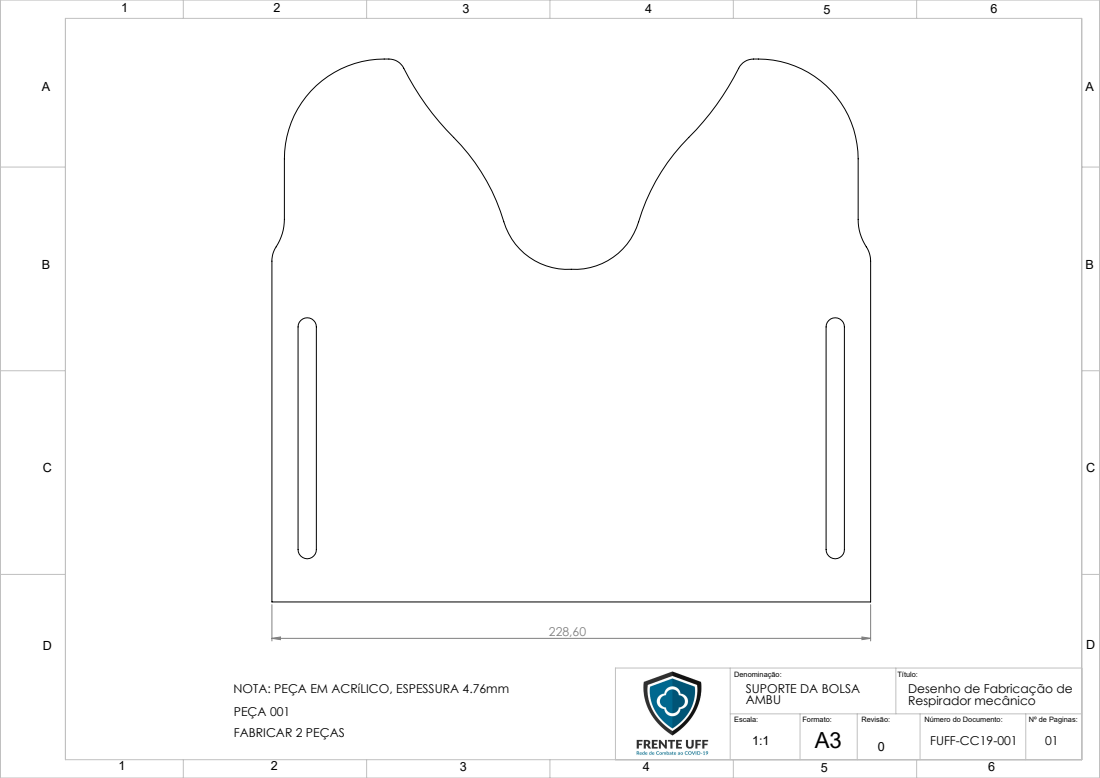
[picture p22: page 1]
NOTA: PEÇA EM ACRíLICO, ESPESSURA 4.76mm; Desenho de Fabricação de; PEÇA 001; FABRICAR 2 PEÇAS

Denominação: SUPORTE DA BOLSA AMBU | Título: Respirador mecânico

Escala: | Formato: | Revisão: | Número do Documento: FUFF-CC19-001 0 1:1 | Nº de Paginas: 01

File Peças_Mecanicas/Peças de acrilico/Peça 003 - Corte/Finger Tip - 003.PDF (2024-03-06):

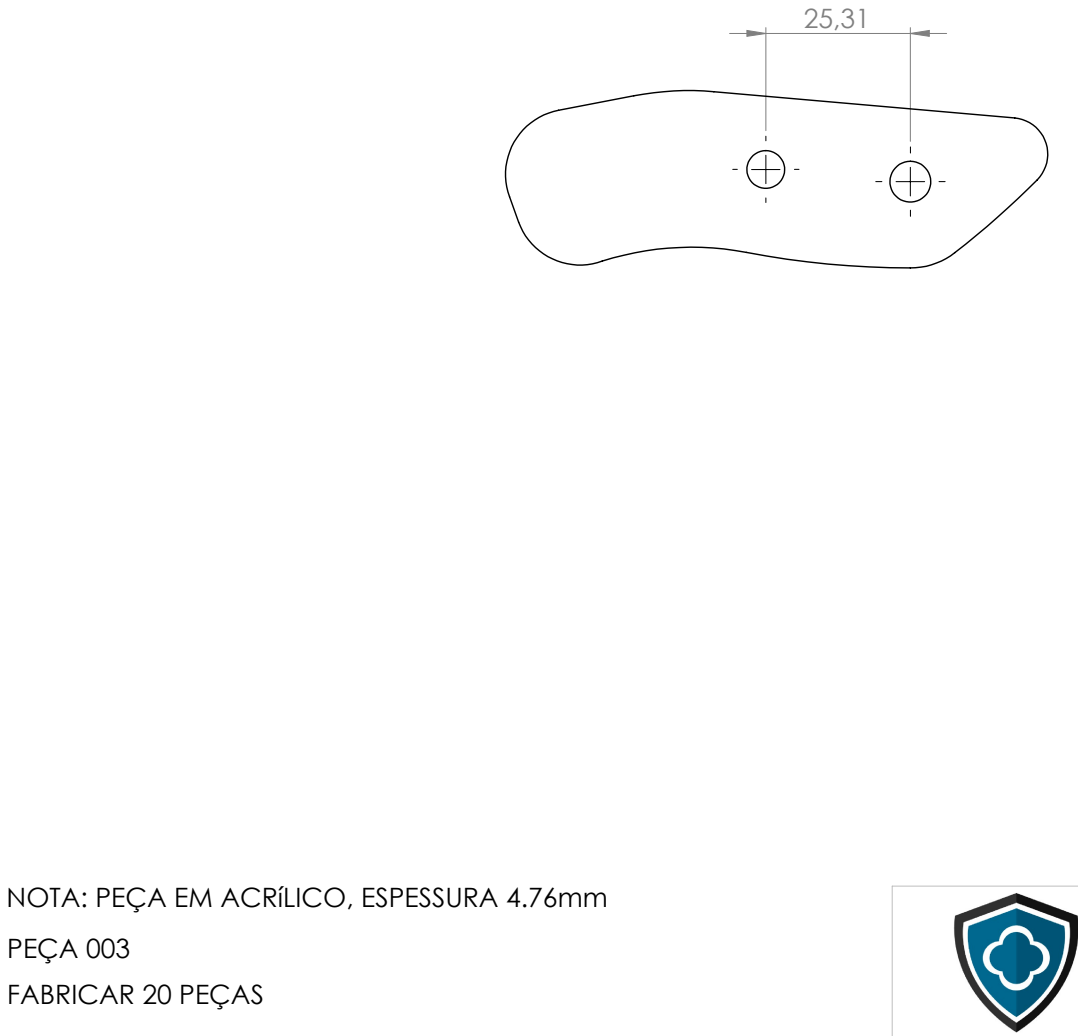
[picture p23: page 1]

NOTA: PEÇA EM ACRíLICO, ESPESSURA 4.76mm
PEÇA 003
FABRICAR 20 PEÇAS

Denominação: COMPONENTE PERIFERICO DA GARRA | Título: Desenho de Fabricação de Respirador mecânico

Escala: 1:1 | Formato: A3 | Revisão: | Número do Documento: FUFF-CC19-001 | Nº de Paginas: 03 0

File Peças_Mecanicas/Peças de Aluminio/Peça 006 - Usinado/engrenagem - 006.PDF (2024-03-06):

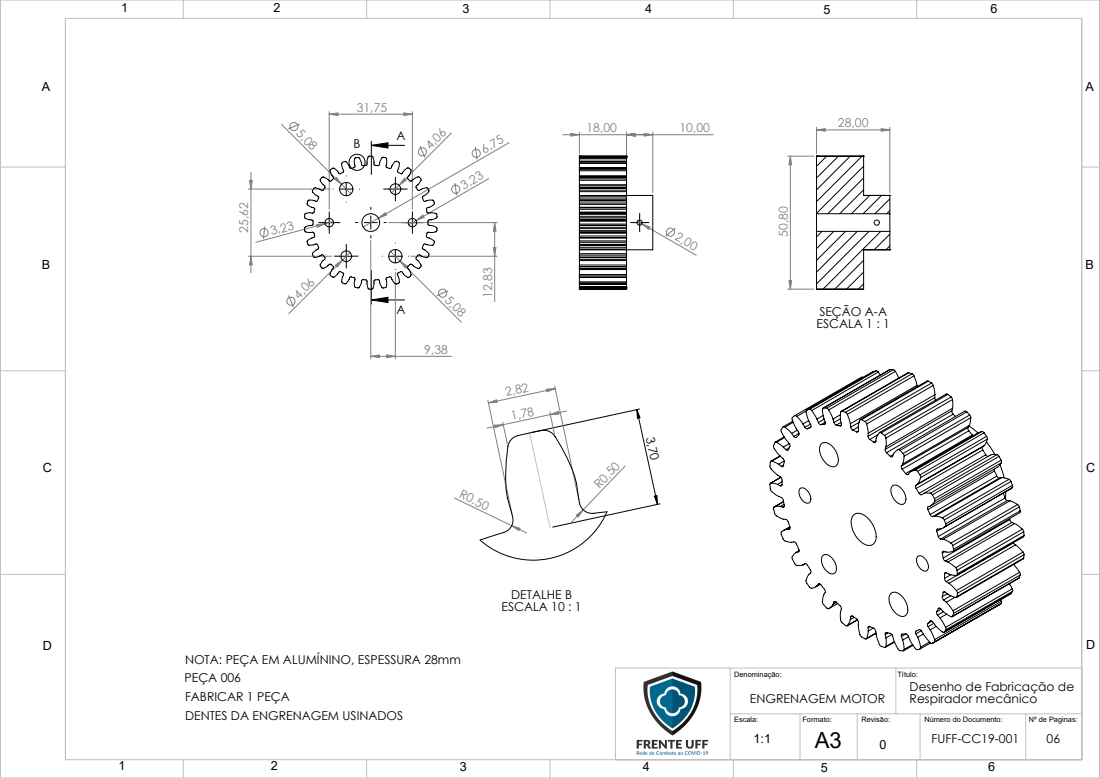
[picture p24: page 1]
SEÇÃO A-A ESCALA 1 : 1; DETALHE B ESCALA 10 : 1; FABRICAR 1 PEÇA; Desenho de Fabricação de

NOTA: PEÇA EM ALUMÍNINO, ESPESSURA 28mm
PEÇA 006
DENTES DA ENGRENAGEM USINADOS

Denominação: ENGRENAGEM MOTOR | Título: Respirador mecânico

Escala: | Formato: A3 | Revisão: | Número do Documento: FUFF-CC19-001 0 1:1 | Nº de Paginas: 06

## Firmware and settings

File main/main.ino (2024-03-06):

//Incluindo bibliotecas
#include <avr/io.h>
#include <util/delay.h>
#include <avr/interrupt.h>
#include "board.h"
#include "int.c"
#include "isr_BOTAO.c"
#include "isr_ENCODER.c"
#include "isr_HOMING.c"
#include "globals.h"
#include "i2c_master.h"
#include "lcd8bit.h"
#include "teste.c"

//Protótipo da função para debug
void func_teste(void);

int main(void) {

  //Habilita as portas
  initPIN();

  //Habilita Display LCD
  lcd_init();
  stdout = lcd_file_out();
  i2c_init();

  printf("Hello World!");

  //Configurando pino de interrupção para botão de silenciar alarme
  initInterrupt();

  while (1) {

    // Potenciômetro BPM (ADC0)
    adc_value1 = initADC(PIN_POT_BPM);
    // Sensor de pressão (ADC1)
    adc_value2 = initADC(PIN_POT_IE);
    // Sensor de pressão (ADC2)
    adc_value3 = initADC(PIN_POT_TIDAL);
    // Sensor de pressão (ADC3)
    adc_value4 = initADC(PIN_POT_THRESHOLD);
    // Sensor de pressão (ADC4)
    adc_value0 = initADC(PIN_SENSOR_PRESSAO);

    //Função para debug
    func_teste();

    // Escreve no Display LCD
    printf("%8d", adc_value1);
  }

}

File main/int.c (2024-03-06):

#include <avr/io.h>
#include <avr/interrupt.h>
#include "board.h"

//Habilitando portas de entrada
void initPIN(void) {

  // Configurando portas de saída
  DDRB = (1 << PIN_BUZZER);
  DDRH = ((1 << PIN_MOTOR_CTRL) | (1 << PIN_MOTOR_DIR) | (1 << PIN_MOTOR_EN));

  // Configurando pull-up das portas de entrada
  PORTB = ((1 << PIN_BOTAO_MODO) | (1 << PIN_BOTAO_CONFIRMAR) | (1 << PIN_BOTAO_SILENCIAR));
  PORTJ = (1 << PIN_SENSOR_FIM_CURSO);

}

//Habilita as interrupções
void initInterrupt(void) {
  cli();
  //Pinos INT
  EICRA |= ((1 << ISC20) | (1 << ISC30));
  EIMSK |= ((1 << INT2) | (1 << INT3));
  //Pinos PCINT
  PCICR |= ((1 << PCIE0) | (1 << PCIE1)); // Habilita a porta B, J para interrupção
  PCMSK0 = ((1 << PCINT6) | (1 << PCINT7)); // Habilita o pino PB6 (PCINT6), PB7 (PCINT7)
  PCMSK1 = (1 << PCINT10); // Habilita a porta PJ1
  sei();

}

// Configura leitura analógica
uint16_t initADC(uint8_t channel) {
  ADMUX = ((1 << REFS0) | channel); // Tensão de entrada de referência avcc = 5V
  ADCSRA = ((1 << ADPS0) | (1 << ADPS1) | (1 << ADPS2));
  ADCSRA |= (1 << ADEN);
  ADCSRA |= (1 << ADSC);       // start conversion
  loop_until_bit_is_clear(ADCSRA, ADSC); // wait for conversion complete
  return ADC;
}

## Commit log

2024-03-06 main
    code/add-arduino-codes
2024-03-06 circuit
    circuit/add-circuit
    [eventArduinoMega.xlsx]
2024-03-06 mechanical
    mechanical/add-parts
    [Bag Support End - 001.DXF, Bag Support End - 001.SLDDRW, Finger - 007.DXF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]
